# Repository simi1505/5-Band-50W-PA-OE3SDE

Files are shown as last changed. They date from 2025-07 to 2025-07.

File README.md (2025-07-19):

# 5-Band-50W-PA-OE3SDE
 50W 5-Band (80m, 40m, 30m, 20m and 10m) SSB PA inspired by W6JL.

## Block Diagram

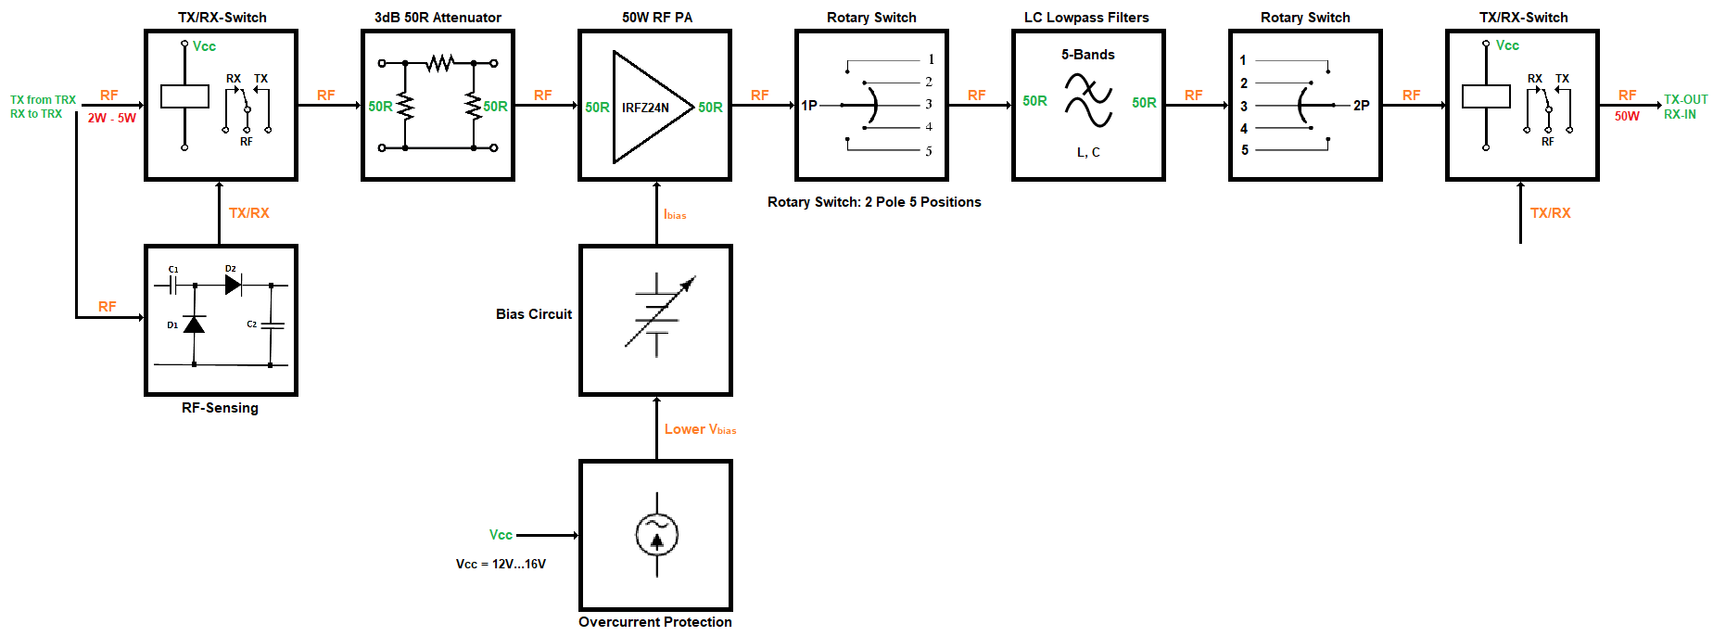
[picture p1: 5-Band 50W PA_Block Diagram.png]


**Figure 1**: Block diagram of 50W 5-Band (80m, 40m, 30m, 20m and 10m) SSB PA.

## Results

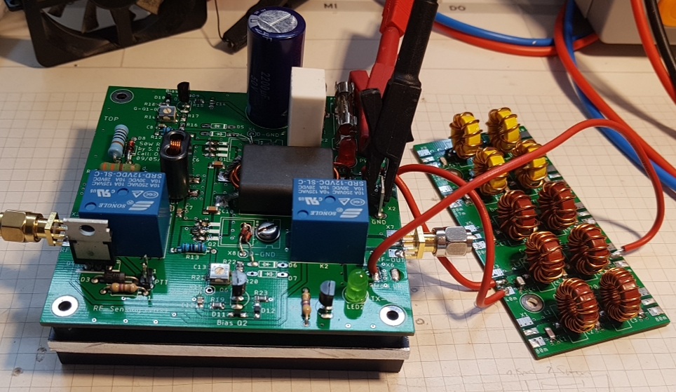
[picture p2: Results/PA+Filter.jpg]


**Figure 2**: Setup of 50W PA and LC lowpass filter.

## LC Lowpass Filters

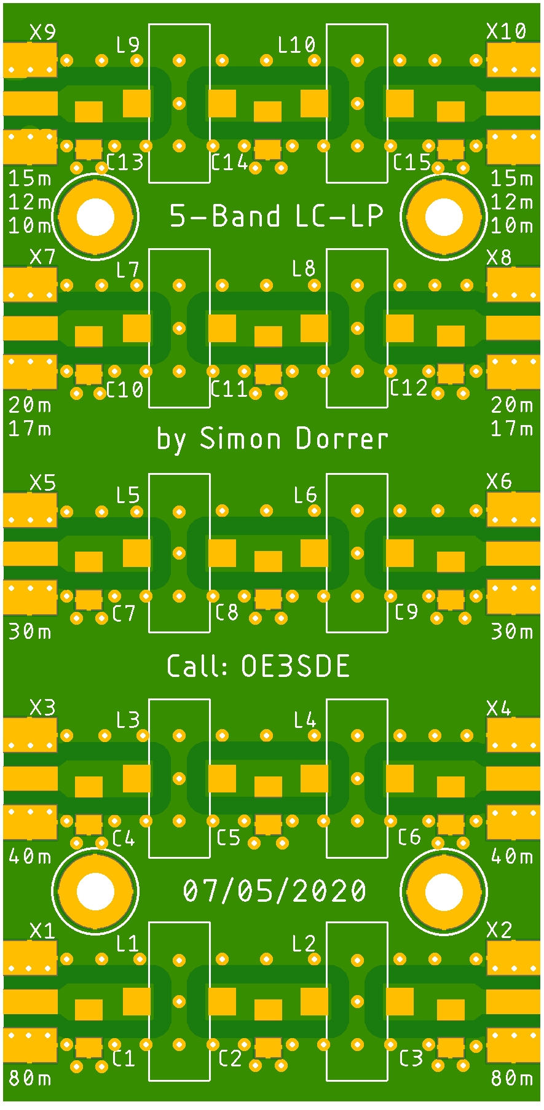
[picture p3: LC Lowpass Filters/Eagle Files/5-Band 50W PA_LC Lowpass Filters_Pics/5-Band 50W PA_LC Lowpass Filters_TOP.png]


**Figure 3**: Top view of LC lowpass filter PCB.



**Figure 4**: Measurement of LC lowpass filter with NanoVNA.

## **50W Power Amplifier**

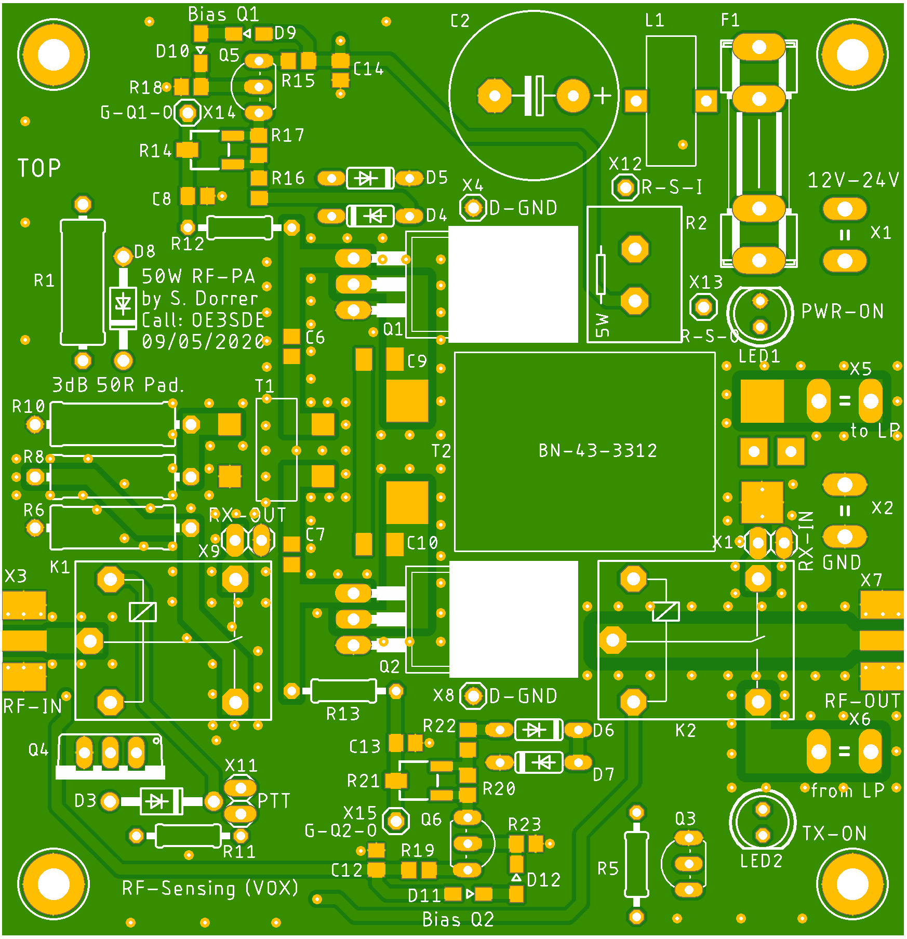
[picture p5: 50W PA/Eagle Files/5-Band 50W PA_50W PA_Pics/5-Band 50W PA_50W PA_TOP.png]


**Figure 5**: Top view of 50W PA PCB.

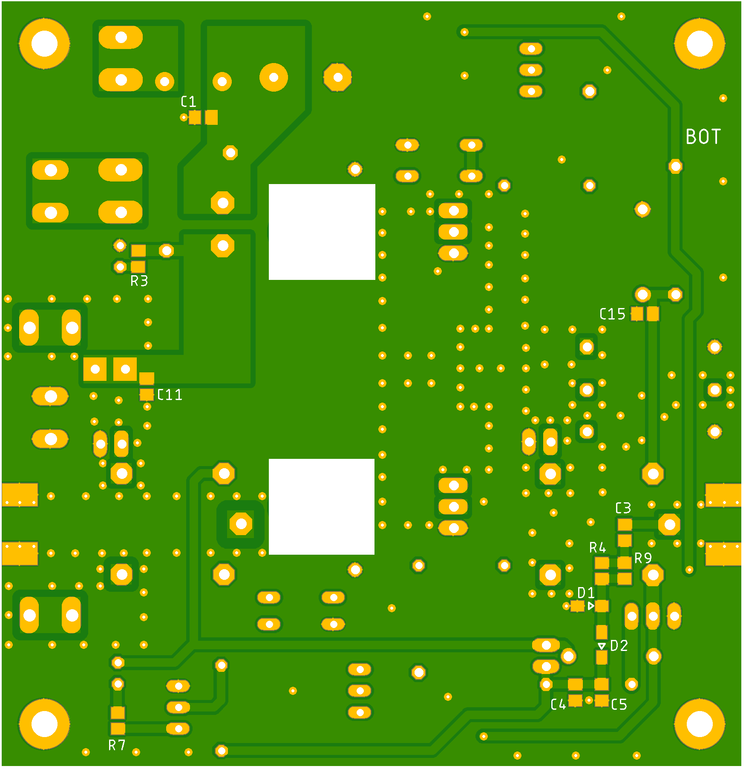
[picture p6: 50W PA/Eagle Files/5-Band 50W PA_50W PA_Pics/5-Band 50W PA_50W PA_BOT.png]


**Figure 6**: Bottom view of 50W PA PCB.

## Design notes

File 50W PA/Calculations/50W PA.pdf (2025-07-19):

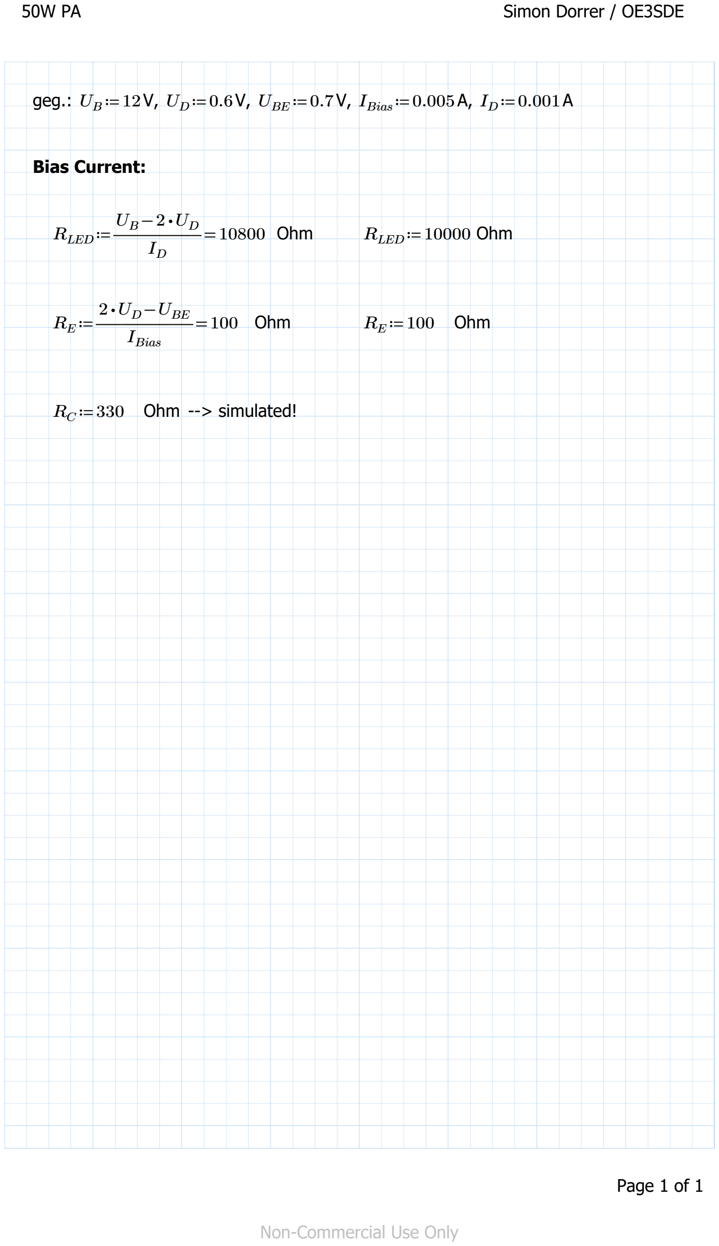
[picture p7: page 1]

50W PA | Simon Dorrer / OE3SDE

geg.: UB≔12V, UD≔0.6V, UBE≔0.7V, IBias≔0.005A, ID≔0.001A

Bias Current:

RLED≔――――=

UB −2 ⋅UD
ID

10800 Ohm RLED≔10000 Ohm

RE≔――――=

2 ⋅UD −UBE

IBias

100 Ohm | RE≔100 Ohm

RC≔330 Ohm --> simulated!

Non-Commercial Use Only

Page 1 of 1

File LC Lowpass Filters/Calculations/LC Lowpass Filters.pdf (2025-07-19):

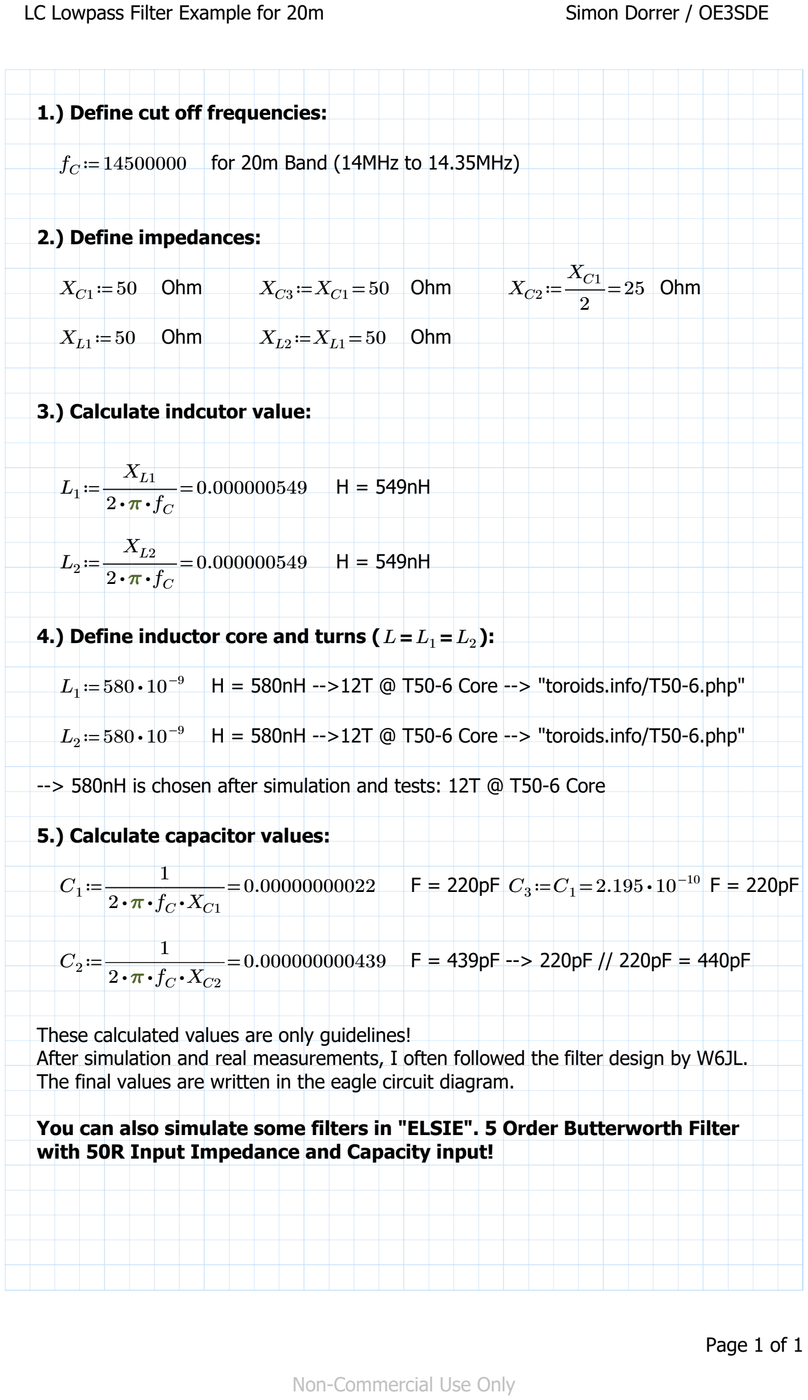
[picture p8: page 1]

LC Lowpass Filter Example for 20m | Simon Dorrer / OE3SDE

1.) Define cut off frequencies:

fC≔14500000 for 20m Band (14MHz to 14.35MHz)

2.) Define impedances:
XC1≔50 Ohm | XC3≔XC1=50 Ohm | XC2≔――= XC1
| | 2

### 25 Ohm

XL1≔50 Ohm XL2≔XL1=50 Ohm

3.) Calculate indcutor value:

L1≔―――=

XL1
2 ⋅π⋅ fC

0.000000549 H = 549nH

L2≔―――=

XL2
2 ⋅π⋅ fC
0.000000549 | H = 549nH
4.) Define inductor core and turns (L＝L ＝ ): 1 | L2

L1≔580 ⋅ 10⁻⁹ H = 580nH -->12T @ T50-6 Core --> "toroids.info/T50-6.php"

L2≔580 ⋅ 10⁻⁹ H = 580nH -->12T @ T50-6 Core --> "toroids.info/T50-6.php"

--> 580nH is chosen after simulation and tests: 12T @ T50-6 Core

5.) Calculate capacitor values:

C1≔―――――=

1
2 ⋅π⋅ fC ⋅XC1

0.00000000022 F = 220pF C3≔C1=2.195 ⋅ 10⁻¹⁰ F = 220pF

C2≔―――――=

1
2 ⋅π⋅ fC ⋅XC2

0.000000000439 F = 439pF --> 220pF // 220pF = 440pF

These calculated values are only guidelines!
After simulation and real measurements, I often followed the filter design by W6JL. The final values are written in the eagle circuit diagram.

You can also simulate some filters in "ELSIE". 5 Order Butterworth Filter with 50R Input Impedance and Capacity input!

Non-Commercial Use Only

Page 1 of 1

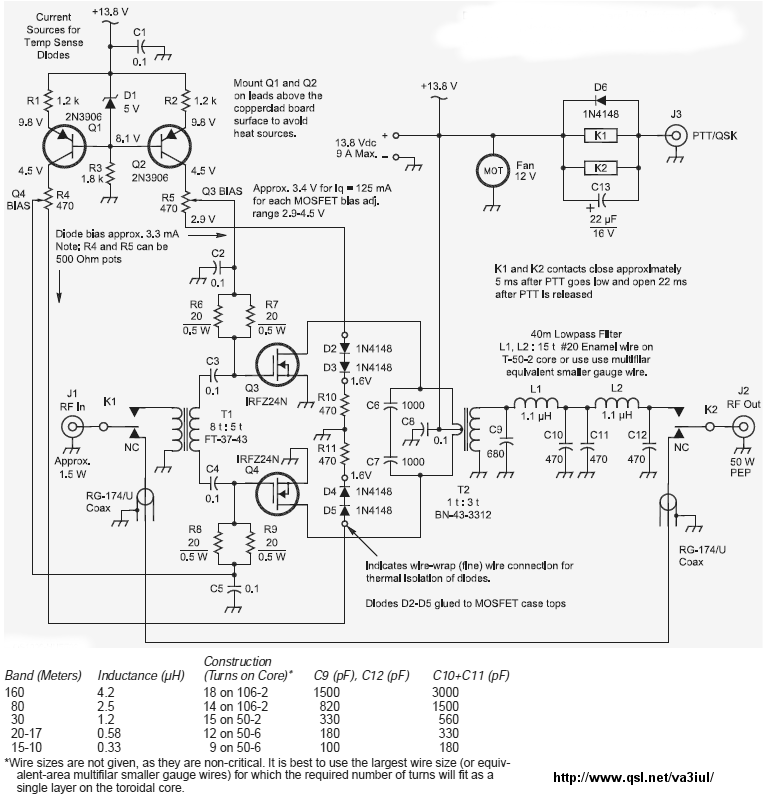
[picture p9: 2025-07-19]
5-Band 50W PA W6JL.gif

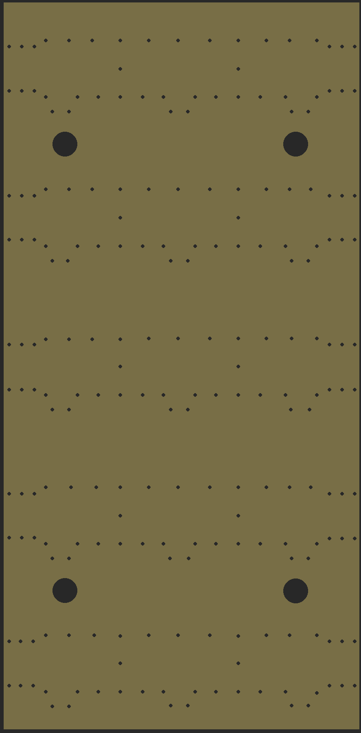
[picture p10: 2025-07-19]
LC Lowpass Filters/Eagle Files/5-Band 50W PA_LC Lowpass Filters_Pics/5-Band 50W PA_LC Lowpass Filters_Drills.png

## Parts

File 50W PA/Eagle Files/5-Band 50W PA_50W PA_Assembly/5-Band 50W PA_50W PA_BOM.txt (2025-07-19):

Partlist exported from E:/Simon Dorrer/DIY Projekte/Amateurfunkprojekte/DIY KITs/HF/5-Band 50W PA/50W PA/Eagle Files/5-Band 50W PA_50W PA.sch at 16/06/2020 14:54

Qty Value               Device                      Package                  Parts                                       Description                                                     MF                 MPN          OC_FARNELL OC_NEWARK POPULARITY SPICEPREFIX
1   0.10R/5W            RMNS-5                      MNS-5                    R2                                          Power Resitor                                                                                   unknown    unknown                         
2   100R                R-EU_R0805                  R0805                    R15, R19                                    RESISTOR, European symbol                                                                                            86         R          
1   100R/1W             R-EU_0414/15                0414/15                  R1                                          RESISTOR, European symbol                                                                                            0          R          
10  100nF               C-EUC0805                   C0805                    C1, C4, C6, C7, C8, C11, C12, C13, C14, C15 CAPACITOR, European symbol                                                                                           88         C          
2   10R                 R-EU_0207/10                0207/10                  R12, R13                                    RESISTOR, European symbol                                                                                            81         R          
2   10k                 R-EU_R0805                  R0805                    R18, R23                                    RESISTOR, European symbol                                                                                            86         R          
1   12V                 ST6,3                       ST6,3                    X1                                          RIBBON CABLE CONNECTOR                                                                          unknown    unknown                         
1   18R/1W              R-EU_0414/15                0414/15                  R8                                          RESISTOR, European symbol                                                                                            0          R          
1   1N4004              1N4004                      DO41-10                  D3                                          DIODE                                                                                                                                      
4   1N4148              1N4148DO35-7                DO35-7                   D4, D5, D6, D7                              DIODE                                                                                                                                      
6   1N4148              DIODE-SOD323-W              SOD323-W                 D1, D2, D9, D10, D11, D12                   DIODE                                                                                                                                      
1   1N4740A             1N4728                      DO41Z10                  D8                                          Z DIODE                                                                                                                                    
3   1k                  R-EU_R0805                  R0805                    R7, R17, R20                                RESISTOR, European symbol                                                                                            86         R          
2   1k                  TRIM_EU-3223G               3223G                    R14, R21                                    POTENTIOMETER                                                                                                                              
1   1nF                 C-EUC0805                   C0805                    C3                                          CAPACITOR, European symbol                                                                                           88         C          
2   1nF                 C-EUC1206K                  C1206K                   C9, C10                                     CAPACITOR, European symbol                                                                                           13         C          
1   1uF                 C-EUC0805                   C0805                    C5                                          CAPACITOR, European symbol                                                                                           88         C          
1   2200uF/25V          CPOL-EUE7.5-16              E7,5-16                  C2                                          POLARIZED CAPACITOR, European symbol                                                                                 4          C          
1   2k                  R-EU_R0805                  R0805                    R3                                          RESISTOR, European symbol                                                                                            86         R          
2   300R/1W             R-EU_0414/15                0414/15                  R6, R10                                     RESISTOR, European symbol                                                                                            0          R          
2   330R                R-EU_R0805                  R0805                    R16, R22                                    RESISTOR, European symbol                                                                                            86         R          
2   470R/0.5W           R-EU_0207/10                0207/10                  R5, R11                                     RESISTOR, European symbol                                                                                            81         R          
1   10A                  SHK20L                      SHK20L                   F1                                          FUSE HOLDER 5 x 20 mm, SH contact, SHH1 Schukat, E1073 Buerklin                                 unknown    unknown                         
2   680R                R-EU_R0805                  R0805                    R4, R9                                      RESISTOR, European symbol                                                                                            86         R          
1   BC547B              BC547B-NPN-TO92-CBE         TO92-CBE                 Q3                                          NPN Transistror                                                                                                                            
2   BC557B              BC557B                      TO92-EBC                 Q5, Q6                                      PNP Transistror                                                                                                                            
1   BN-43-3312          BN-43-3312CENTERTAP         BN-43-3312CENTERTAPSMD   T2                                                                                                                                                                                     
1   FT37-43             FT37-43                     FT37-43SMD               T1                                                                                                                                                                                     
1   G-Q1_OUT            PINHD-1X1                   1X01                     X14                                         PIN HEADER                                                                                                                                 
1   G-Q2_OUT            PINHD-1X1                   1X01                     X15                                         PIN HEADER                                                                                                                                 
4   GND                 MOUNT-PAD-ROUND3.0          3,0-PAD                  H1, H2, H3, H4                              MOUNTING PAD, round                                                                                                                        
2   GND                 PINHD-1X1                   1X01                     X4, X8                                      PIN HEADER                                                                                                                                 
1   GND                 ST6,3                       ST6,3                    X2                                          RIBBON CABLE CONNECTOR                                                                          unknown    unknown                         
2   IRFZ24              IRF510                      TO220                    Q1, Q2                                      N-Channel Enhancement MOSFET (HEXFET); 100V; 5,6A; 0,54Ohm                                                                                 
1   LP-IN               ST6,3                       ST6,3                    X5                                          RIBBON CABLE CONNECTOR                                                                          unknown    unknown                         
1   LP-O                ST6,3                       ST6,3                    X6                                          RIBBON CABLE CONNECTOR                                                                          unknown    unknown                         
1   PTT                 PINHD-1X2                   1X02                     X11                                         PIN HEADER                                                                                                                                 
1   R-Shunt_OUT         PINHD-1X1                   1X01                     X13                                         PIN HEADER                                                                                                                                 
1   RF-IN               SMA-PCB-CON142-0711-821/826 J502-ND-142-0711-821/826 X3                                          SMA 50 Ohm End Launch Jack Receptacle - Round Contact           JOHNSON COMPONENTS 142-0711-821 1019328    16F3627                         
1   RF-OUT              SMA-PCB-CON142-0711-821/826 J502-ND-142-0711-821/826 X7                                          SMA 50 Ohm End Launch Jack Receptacle - Round Contact           JOHNSON COMPONENTS 142-0711-821 1019328    16F3627                         
1   RX-IN               PINHD-1X2                   1X02                     X10                                         PIN HEADER                                                                                                                                 
1   RX-OUT              PINHD-1X2                   1X02                     X9                                          PIN HEADER                                                                                                                                 
1   R_Shunt_IN          PINHD-1X1                   1X01                     X12                                         PIN HEADER                                                                                                                                 
2   Red                 LED5MM                      LED5MM                   LED1, LED2                                  LED                                                                                                                                        
2   SRD-12VDC-SL-C      SRD-12VDC-SL-C              SRD-12VDC-SL-C           K1, K2                                      RELAY                                                                                                                                      
1   TIP31C              TIP41C                      TO220AV                  Q4                                          NPN TRANSISTOR                                                                                                                             
1   RFC T50-6                       T50-6SMD                 L1

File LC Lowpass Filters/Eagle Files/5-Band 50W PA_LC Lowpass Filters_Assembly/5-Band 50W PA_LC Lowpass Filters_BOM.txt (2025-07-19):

Partlist exported from E:/Simon Dorrer/DIY Projekte/Amateurfunkprojekte/DIY KITs/5-Band 50W PA/LC Lowpass Filters/Eagle Files/5-Band 50W PA_LC Lowpass Filters.sch at 19/05/2020 19:35

Qty Value   Device               Package                  Parts               Description                                           MF                 MPN          OC_FARNELL OC_NEWARK POPULARITY SPICEPREFIX
2   1.2uH   T50-6                T50-6SMD                 L3, L4                                                                                                                                               
1   1000pF  C-EUC1206K           C1206K                   C5                  CAPACITOR, European symbol                                                                                 13         C          
1   1500pF  C-EUC1206K           C1206K                   C2                  CAPACITOR, European symbol                                                                                 13         C          
1   164pF   C-EUC1206K           C1206K                   C14                 CAPACITOR, European symbol                                                                                 13         C          
2   180pF   C-EUC1206K           C1206K                   C10, C12            CAPACITOR, European symbol                                                                                 13         C          
2   1uH     T50-6                T50-6SMD                 L5, L6                                                                                                                                               
2   2.5uH   T50-6                T50-6SMD                 L1, L2                                                                                                                                               
3   330pF   C-EUC1206K           C1206K                   C7, C9, C11         CAPACITOR, European symbol                                                                                 13         C          
2   400nH   T50-6                T50-6SMD                 L9, L10                                                                                                                                              
3   560pF   C-EUC1206K           C1206K                   C4, C6, C8          CAPACITOR, European symbol                                                                                 13         C          
2   580nH   T50-6                T50-6SMD                 L7, L8                                                                                                                                               
2   820pF   C-EUC1206K           C1206K                   C1, C3              CAPACITOR, European symbol                                                                                 13         C          
2   82pF    C-EUC1206K           C1206K                   C13, C15            CAPACITOR, European symbol                                                                                 13         C          
4   GND     MOUNT-PAD-ROUND3.0   3,0-PAD                  H1, H2, H3, H4      MOUNTING PAD, round                                                                                                              
5   SMA_IN  SMA-142-0711-821/826 J502-ND-142-0711-821/826 X1, X3, X5, X7, X9  SMA 50 Ohm End Launch Jack Receptacle - Round Contact JOHNSON COMPONENTS 142-0711-821 1019328    16F3627                         
5   SMA_OUT SMA-142-0711-821/826 J502-ND-142-0711-821/826 X2, X4, X6, X8, X10 SMA 50 Ohm End Launch Jack Receptacle - Round Contact JOHNSON COMPONENTS 142-0711-821 1019328    16F3627

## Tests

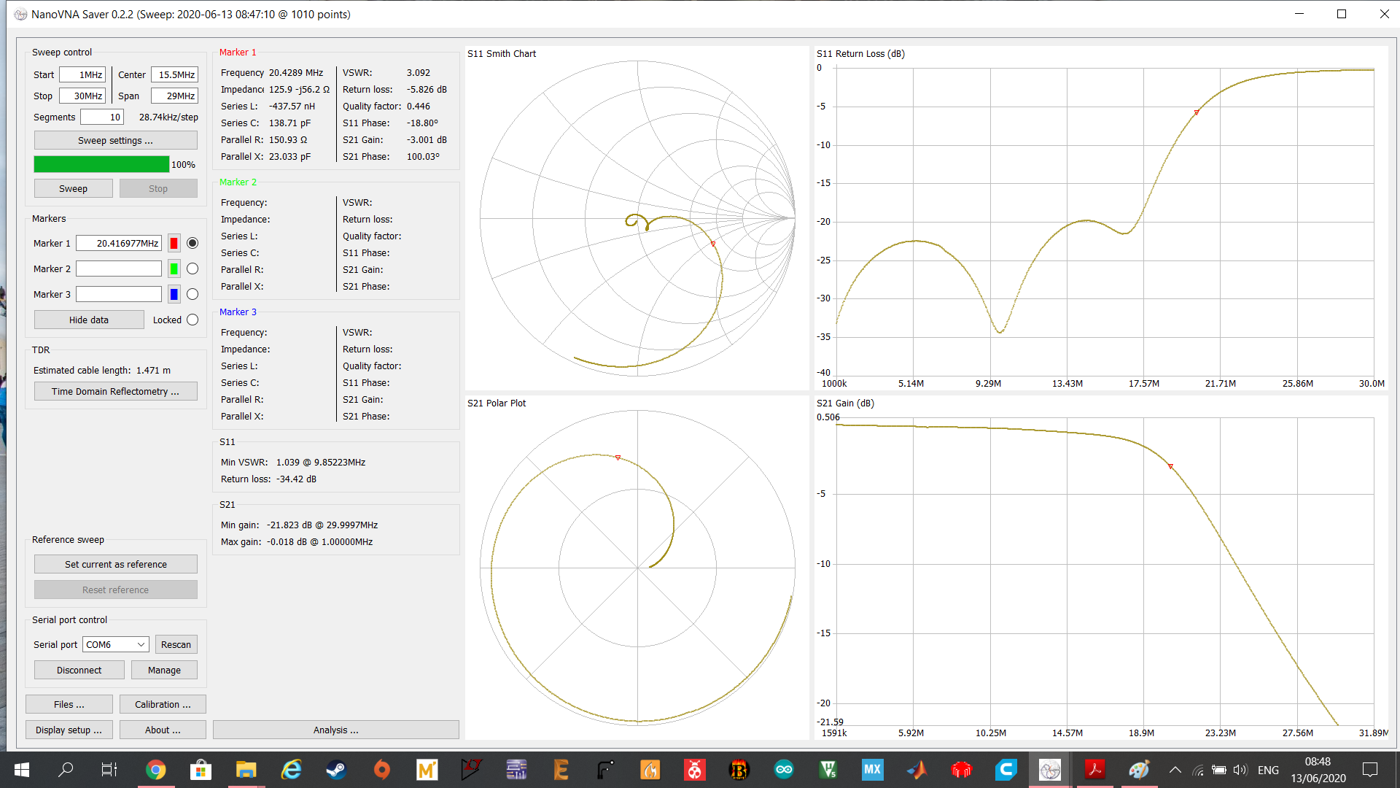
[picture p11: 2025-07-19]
LC Lowpass Filters/Measurements/20m.png

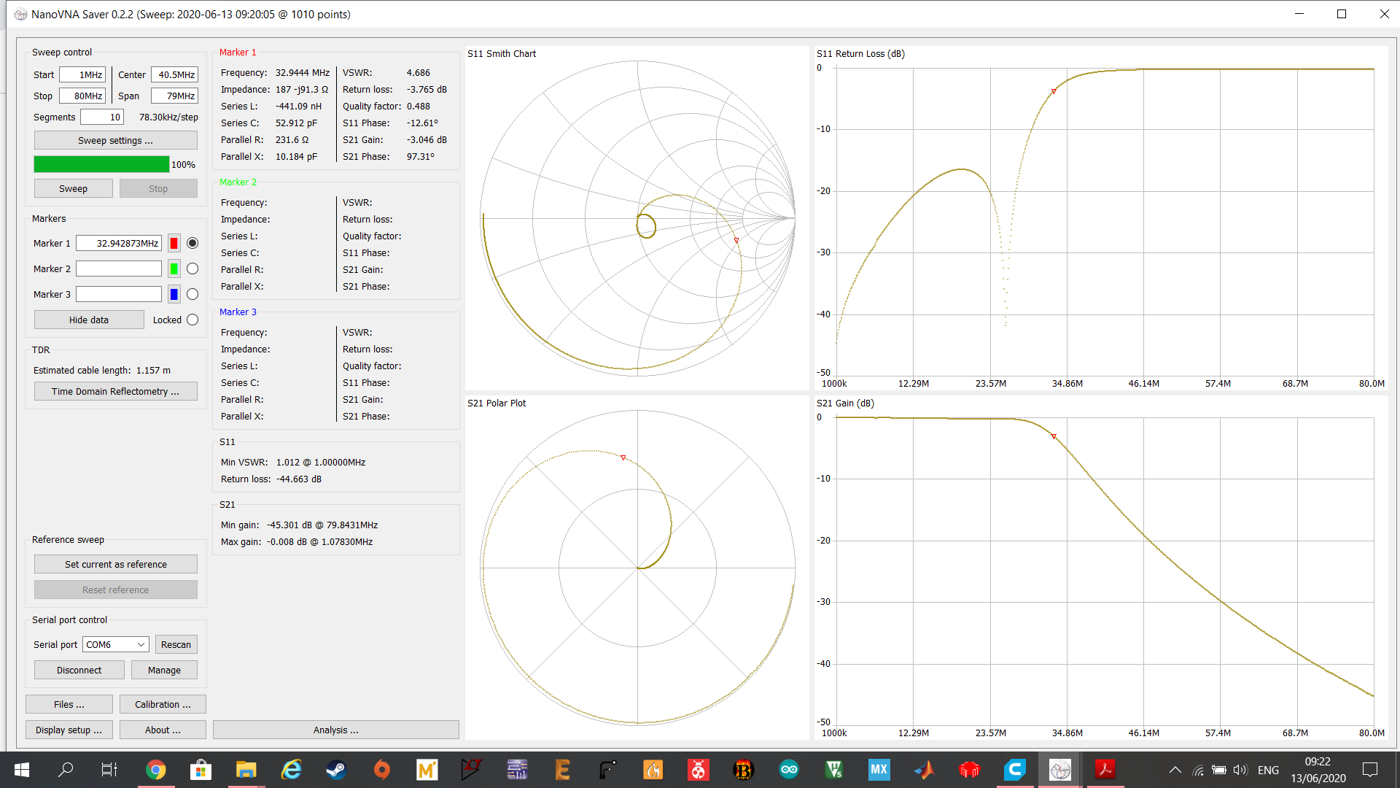
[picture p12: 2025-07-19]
LC Lowpass Filters/Measurements/15-12-10m.png

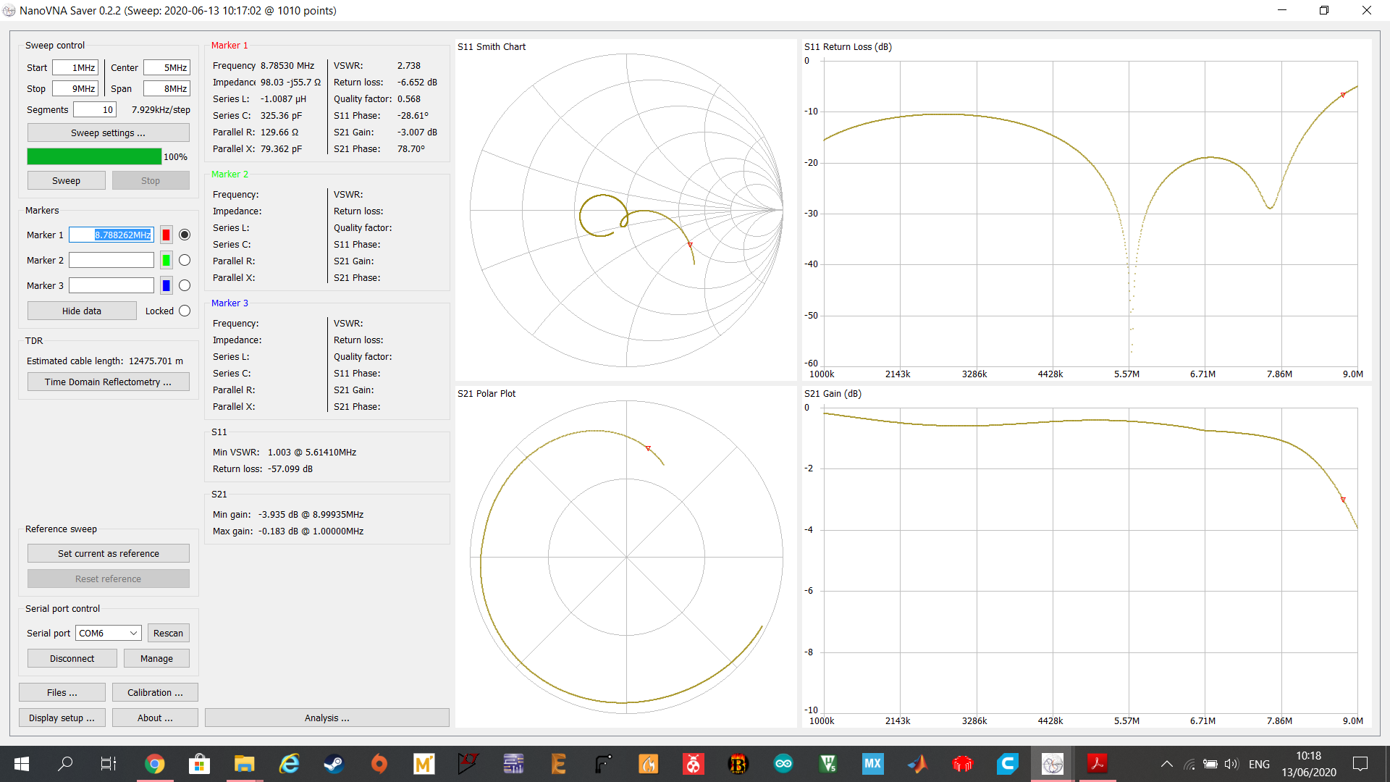
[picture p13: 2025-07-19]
LC Lowpass Filters/Measurements/40m_2.png

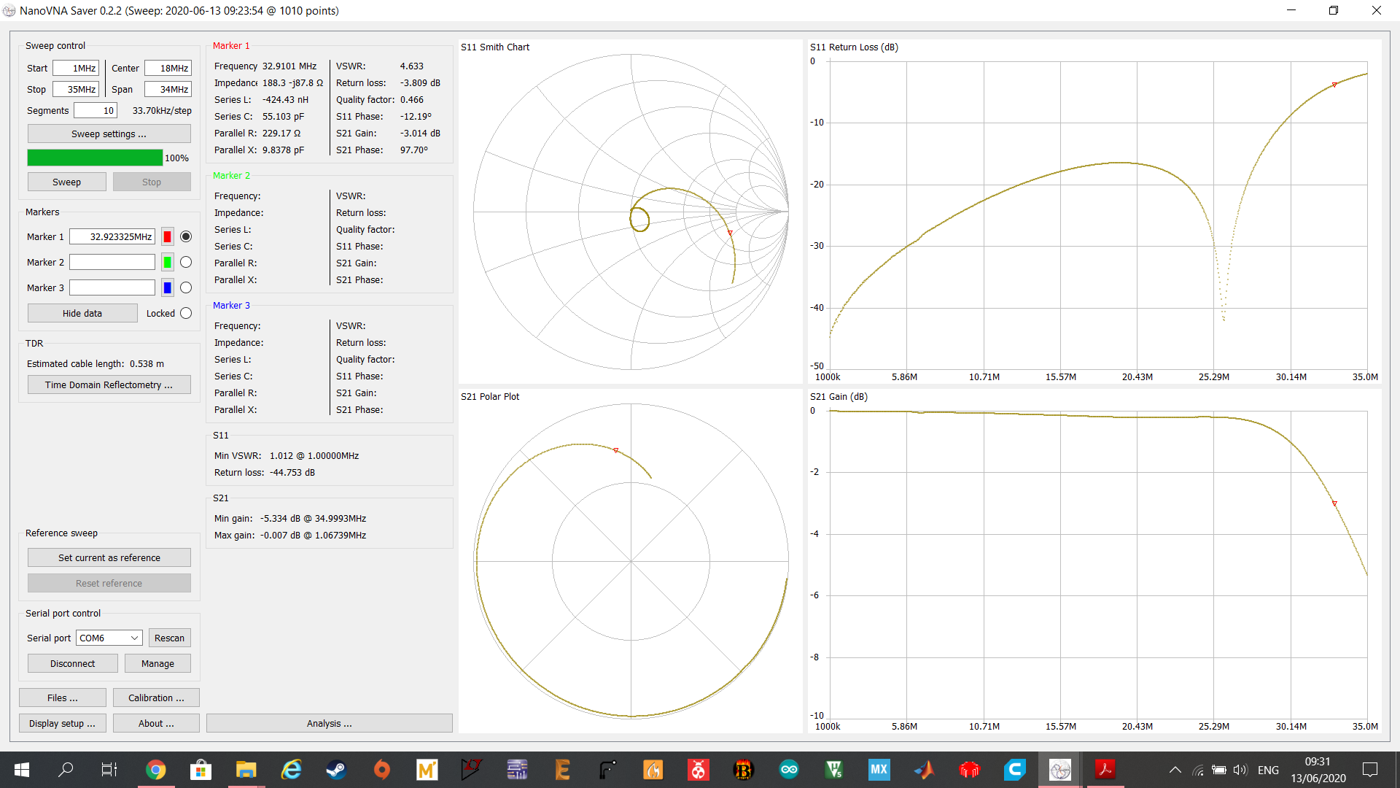
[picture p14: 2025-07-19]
LC Lowpass Filters/Measurements/15-12-10m_2.png

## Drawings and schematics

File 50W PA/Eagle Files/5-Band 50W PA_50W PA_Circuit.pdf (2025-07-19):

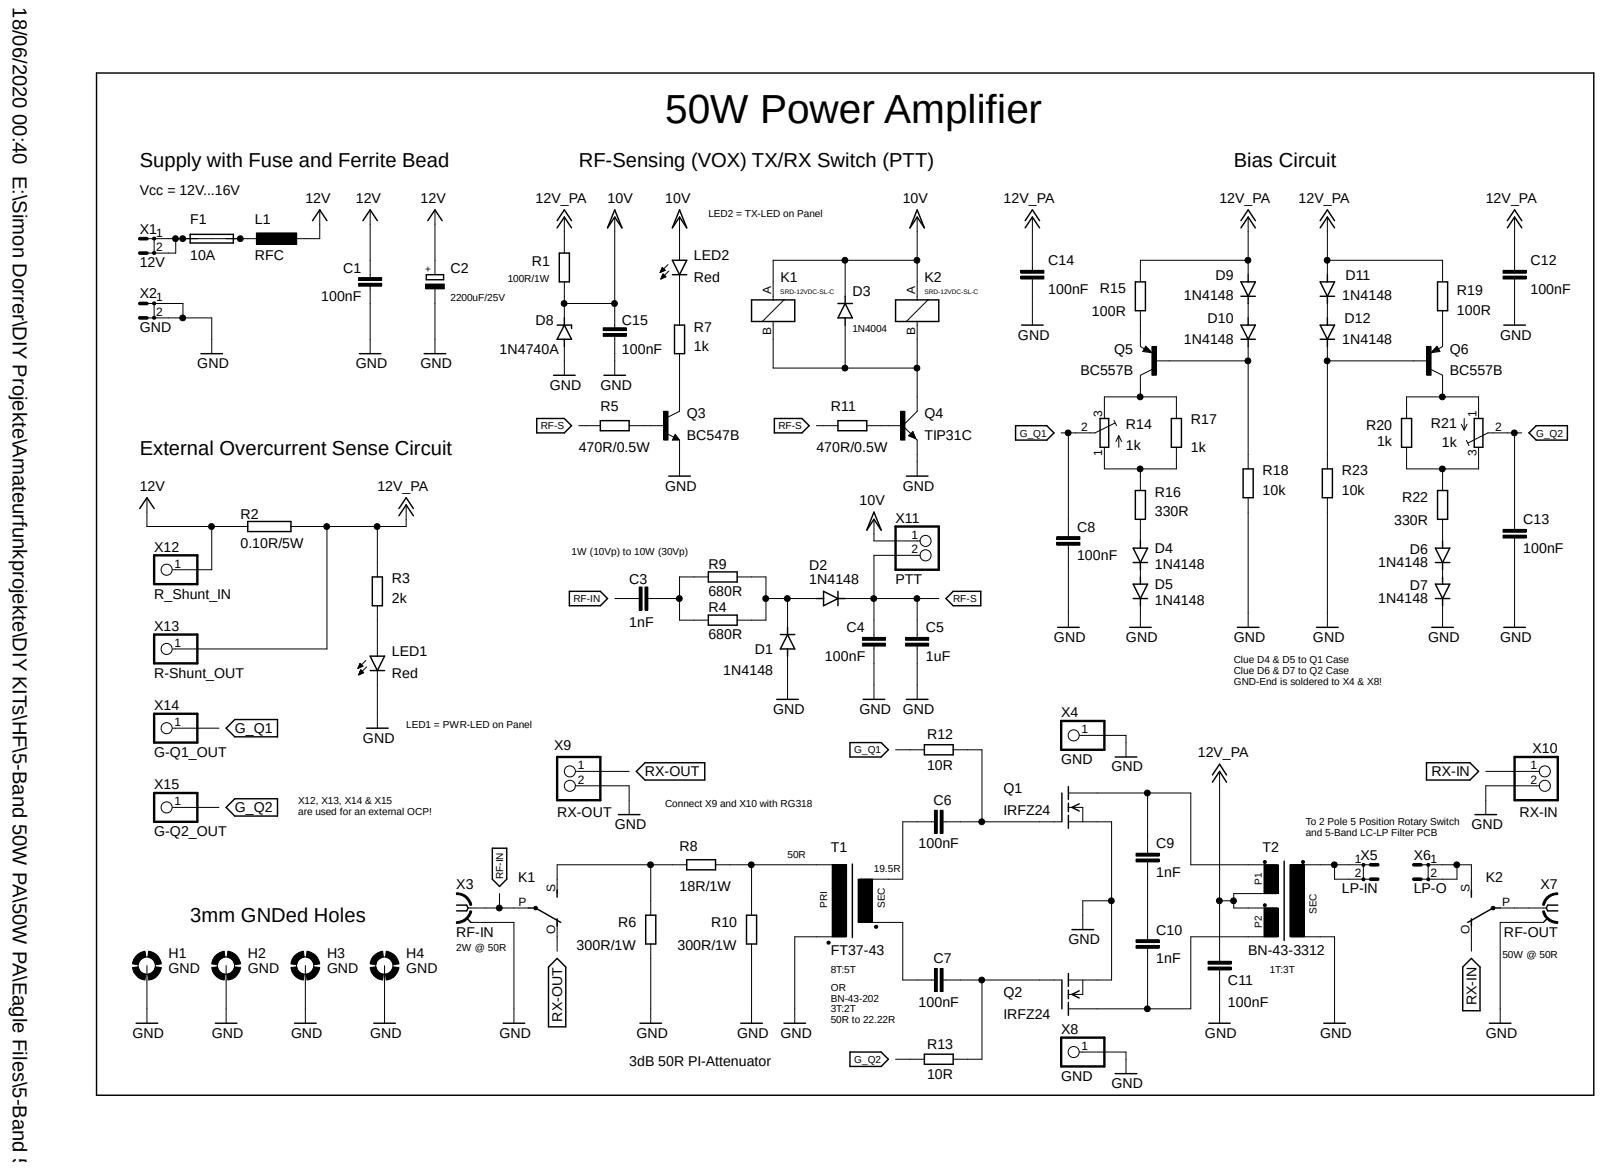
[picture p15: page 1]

18/06/2020 00:40 E:\Simon Dorrer\DIY Projekte\Amateurfunkprojekte\DIY KITs\HF\5-Band 50W PA\50W PA\Eagle Files\5-Band 50W PA_50W PA.sch (Sheet: 1/1) 2W @ 50R 50W @ 50R Clue D4 & D5 to Q1 Case Clue D6 & D7 to Q2 Case GND-End is soldered to X4 & X8! 8T:5T 1T:3T 50W Power Amplifier Supply with Fuse and Ferrite Bead Bias Circuit 3mm GNDed Holes External Overcurrent Sense Circuit RF-Sensing (VOX) TX/RX Switch (PTT) 3dB 50R PI-Attenuator Vcc = 12V...16V To 2 Pole 5 Position Rotary Switch and 5-Band LC-LP Filter PCB LED1 = PWR-LED on Panel 1W (10Vp) to 10W (30Vp) LED2 = TX-LED on Panel Connect X9 and X10 with RG318 X12, X13, X14 & X15 are used for an external OCP! 50R 19.5R ORBN-43-202 3T:2T 50R to 22.22R GND 100nF GND 12V IRFZ24 IRFZ24 RF-IN RF-OUT GND 100nF 100nF GND 100nF GND BC557B BC557B GND 2200uF/25V GND 100nF 100nF 100R 100R 1k 1k 1k 1k 330R 330R 1N4148 1N4148 1N4148 1N4148 GND GND GND GND 10k GND 10R 10R GND GND GND GND GND GND GND GND GND 18R/1W 300R/1W 300R/1W GND GND GND 1N4004 GND 470R/0.5W 1N4148 1N4148 100nF 1uF GND GND 1nF GND GND100nF 10A 12V GND RFC BC547B 470R/0.5W 1kRed 12V GND GND 2kRed GND LP-IN LP-O 12V_PA 12V_PA FT37-43 BN-43-3312 1nF 1nF GND GND GND TIP31C GND100nF GND GND 10k GND 680R 680R PTT 12V_PA 12V_PA 12V_PA 12V_PA 1N4740A 12V_PA GND 10V 10V 10V 0.10R/5W 100nF GND 10V 1N4148 1N4148 1N4148 1N4148 SRD-12VDC-SL-C SRD-12VDC-SL-C RX-OUT RX-IN R_Shunt_IN R-Shunt_OUT G-Q1_OUT G-Q2_OUT 12V 12V 100R/1W C1 Q1 Q2 X3 X7 C6 C7 C11 Q5 Q6 C2 C8 C13 R15 R19 R17 R20

RX-OUT

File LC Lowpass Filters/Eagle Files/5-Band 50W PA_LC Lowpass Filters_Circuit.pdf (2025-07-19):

23T @ T50-2 | 23T @ T50-2 5-Band LC Lowpass Filters

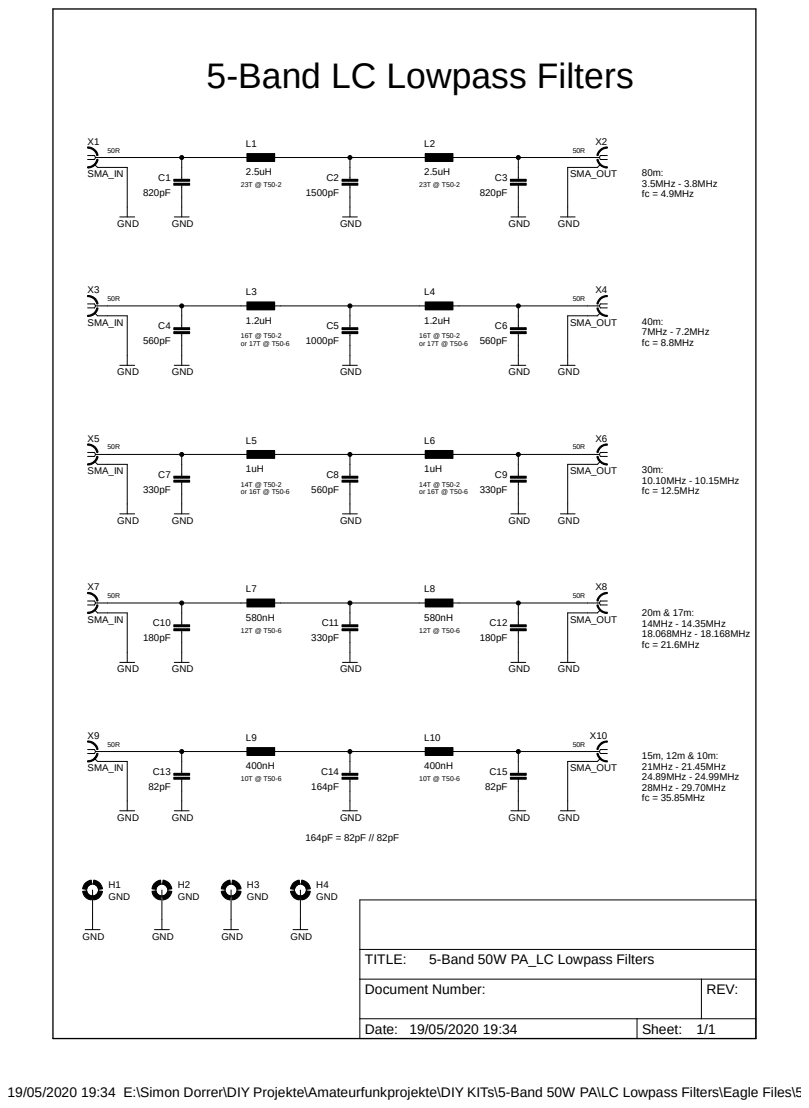
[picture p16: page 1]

Document Number: | REV:

Date: 19/05/2020 19:34 | Sheet: 1/1

19/05/2020 19:34 E:\Simon Dorrer\DIY Projekte\Amateurfunkprojekte\DIY KITs\5-Band 50W PA\LC Lowpass Filters\Eagle Files\5-Band 50W PA_LC Lowpass Filters.sch (Sheet: 1/1)

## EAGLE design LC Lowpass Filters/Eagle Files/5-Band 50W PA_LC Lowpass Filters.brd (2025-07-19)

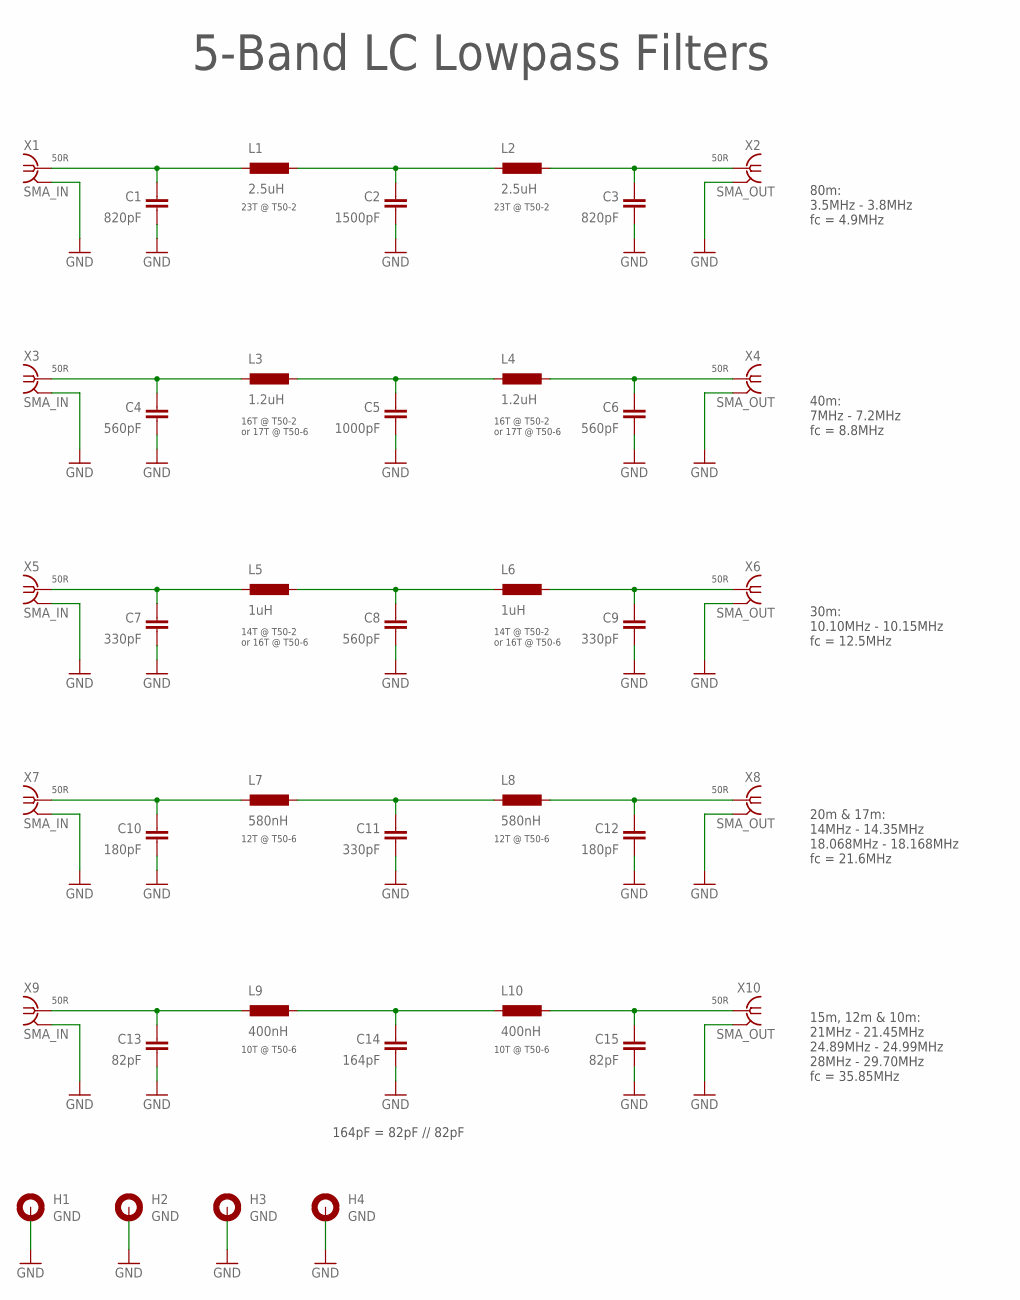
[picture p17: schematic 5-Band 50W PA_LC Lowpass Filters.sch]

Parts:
C1, C3: 820pF; C1206K
C2: 1500pF; C1206K
C4, C6, C8: 560pF; C1206K
C5: 1000pF; C1206K
C7, C9, C11: 330pF; C1206K
C10, C12: 180pF; C1206K
C13, C15: 82pF; C1206K
C14: 164pF; C1206K
H1, H2, H3, H4: GND; 3,0-PAD
L1, L2: 2.5uH; T50-6SMD
L3, L4: 1.2uH; T50-6SMD
L5, L6: 1uH; T50-6SMD
L7, L8: 580nH; T50-6SMD
L9, L10: 400nH; T50-6SMD
X1, X3, X5, X7, X9: SMA_IN; J502-ND-142-0711-821/826
X2, X4, X6, X8, X10: SMA_OUT; J502-ND-142-0711-821/826

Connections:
GND: C1.1, C2.1, C3.1, C4.1, C5.1, C6.1, C7.1, C8.1, C9.1, C10.1, C11.1, C12.1, C13.1, C14.1, C15.1, H1.B3,0, H2.B3,0, H3.B3,0, H4.B3,0, X1.G@1 (2), X1.G@2 (2), X1.G@3 (2), X1.G@4 (2), X2.G@1 (2), X2.G@2 (2), X2.G@3 (2), X2.G@4 (2), X3.G@1 (2), X3.G@2 (2), X3.G@3 (2), X3.G@4 (2), X4.G@1 (2), X4.G@2 (2), X4.G@3 (2), X4.G@4 (2), X5.G@1 (2), X5.G@2 (2), X5.G@3 (2), X5.G@4 (2), X6.G@1 (2), X6.G@2 (2), X6.G@3 (2), X6.G@4 (2), X7.G@1 (2), X7.G@2 (2), X7.G@3 (2), X7.G@4 (2), X8.G@1 (2), X8.G@2 (2), X8.G@3 (2), X8.G@4 (2), X9.G@1 (2), X9.G@2 (2), X9.G@3 (2), X9.G@4 (2), X10.G@1 (2), X10.G@2 (2), X10.G@3 (2), X10.G@4 (2)
unnamed: C2.2, L1.P$2 (2), L2.P$1 (1)
unnamed: C4.2, L3.P$1 (1), X3.1
unnamed: C3.2, L2.P$2 (2), X2.1
unnamed: C1.2, L1.P$1 (1), X1.1
unnamed: C6.2, L4.P$2 (2), X4.1
unnamed: C5.2, L3.P$2 (2), L4.P$1 (1)
unnamed: C7.2, L5.P$1 (1), X5.1
unnamed: C9.2, L6.P$2 (2), X6.1
unnamed: C8.2, L5.P$2 (2), L6.P$1 (1)
unnamed: C10.2, L7.P$1 (1), X7.1
unnamed: C12.2, L8.P$2 (2), X8.1
unnamed: C11.2, L7.P$2 (2), L8.P$1 (1)
unnamed: C13.2, L9.P$1 (1), X9.1
unnamed: C15.2, L10.P$2 (2), X10.1
unnamed: C14.2, L9.P$2 (2), L10.P$1 (1)

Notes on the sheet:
50R
80m: 3.5MHz - 3.8MHz fc = 4.9MHz
23T @ T50-2
5-Band LC Lowpass Filters
40m: 7MHz - 7.2MHz fc = 8.8MHz
16T @ T50-2 or 17T @ T50-6
30m: 10.10MHz - 10.15MHz fc = 12.5MHz
14T @ T50-2 or 16T @ T50-6
20m & 17m: 14MHz - 14.35MHz 18.068MHz - 18.168MHz fc = 21.6MHz
12T @ T50-6
15m, 12m & 10m: 21MHz - 21.45MHz 24.89MHz - 24.99MHz 28MHz - 29.70MHz fc = 35.85MHz
10T @ T50-6
164pF = 82pF // 82pF

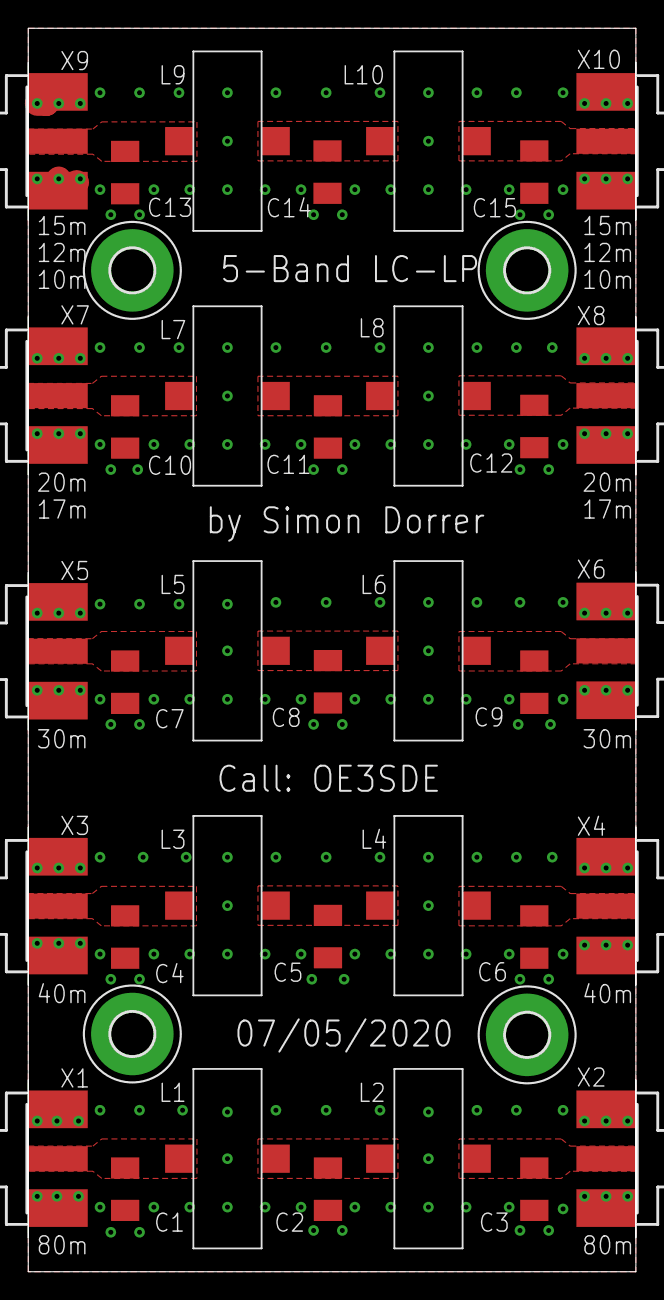
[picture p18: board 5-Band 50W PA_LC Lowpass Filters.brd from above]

Board: 2 copper layers, 43.0 x 88.0 mm, 39 parts (0 on the bottom side), 16 nets.

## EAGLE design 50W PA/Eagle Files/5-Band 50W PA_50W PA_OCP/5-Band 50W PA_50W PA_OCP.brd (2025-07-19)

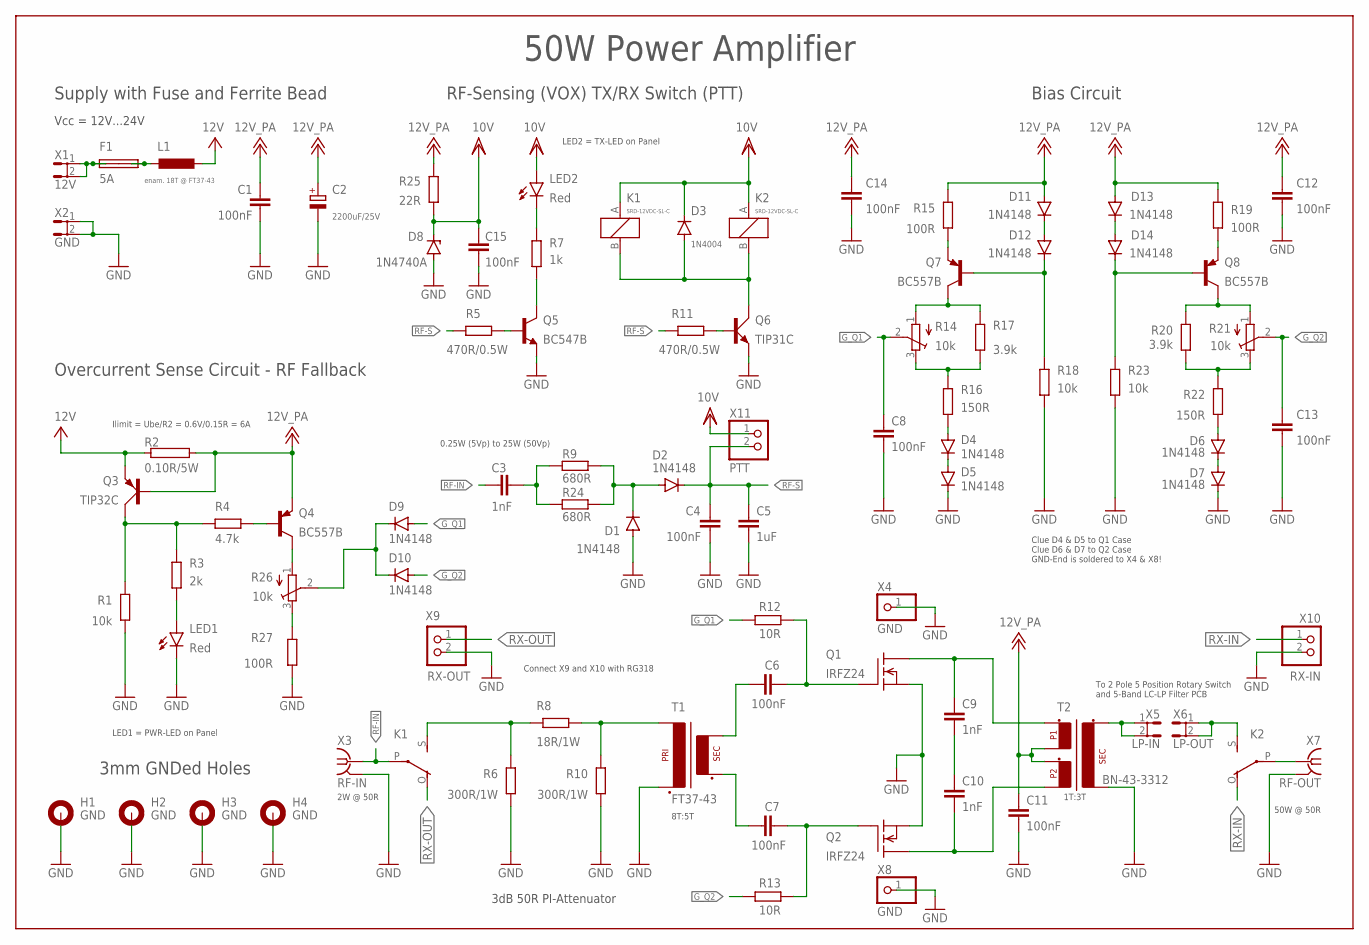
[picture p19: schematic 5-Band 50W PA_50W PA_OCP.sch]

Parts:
C1, C4, C6, C7, C8, C11, C12, C13, C14, C15: 100nF; C0805
C2: 2200uF/25V; E7,5-16
C3: 1nF; C0805
C5: 1uF; C0805
C9, C10: 1nF; C1206K
D1, D2, D9, D10, D11, D12, D13, D14: 1N4148; SOD323-W
D3: 1N4004; DO41-10
D4, D5, D6, D7: 1N4148; DO35-7
D8: 1N4740A; DO41Z10
F1: 5A; SHK20L
H1, H2, H3, H4: GND; 3,0-PAD
K1, K2: SRD-12VDC-SL-C
L1: enam. 18T @ FT37-43; T50-6SMD
LED1, LED2: Red; LED5MM
Q1, Q2: IRFZ24; TO220
Q3: TIP32C; TO220AV
Q4, Q7, Q8: BC557B; TO92-EBC
Q5: BC547B; TO92-CBE
Q6: TIP31C; TO220AV
R1, R18, R23: 10k; R0805
R2: 0.10R/5W; MNS-5
R3: 2k; R0805
R4: 4.7k; R0805
R5, R11: 470R/0.5W; 0207/10
R6, R10: 300R/1W; 0414/15
R7: 1k; R0805
R8: 18R/1W; 0414/15
R9, R24: 680R; R0805
R12, R13: 10R; 0207/10
R14, R21, R26: 10k; 3223G
R15, R19, R27: 100R; R0805
R16, R22: 150R; R0805
R17, R20: 3.9k; R0805
R25: 22R; 0207/10
T1: FT37-43; FT37-43SMD
T2: BN-43-3312; BN-43-3312CENTERTAPSMD
X1: 12V; ST6,3
X2: GND; ST6,3
X3: RF-IN; J502-ND-142-0711-821/826
X4, X8: GND; 1X01
X5: LP-IN; ST6,3
X6: LP-OUT; ST6,3
X7: RF-OUT; J502-ND-142-0711-821/826
X9: RX-OUT; 1X02
X10: RX-IN; 1X02
X11: PTT; 1X02

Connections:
+12V: C1.2, C2.+, C11.2, C12.2, C14.2, D11.A, D13.A, Q3.B, Q4.E, R2.2, R15.2, R19.2, R25.2, T2.P$2 (P1_2), T2.P$3 (P2_1)
GND: C1.1, C2.-, C4.1, C5.1, C8.1, C11.1, C12.1, C13.1, C14.1, C15.1, D1.A, D5.C, D7.C, D8.A, H1.B3,0, H2.B3,0, H3.B3,0, H4.B3,0, LED1.K (C), Q1.3 (S), Q2.3 (S), Q5.E, Q6.E, R1.1, R6.1, R10.1, R18.1, R23.1, R27.1, T1.P$2 (P2), T2.S$2 (S2), X2.1, X2.2, X3.G@1 (GND), X3.G@2 (GND), X3.G@3 (GND), X3.G@4 (GND), X4.1, X7.G@1 (GND), X7.G@2 (GND), X7.G@3 (GND), X7.G@4 (GND), X8.1, X9.2, X10.2
G_Q1: C8.2, D9.A, R12.2, R14.2 (S)
G_Q2: C13.2, D10.A, R13.2, R21.2 (S)
unnamed: C6.2, T1.S$1 (S1)
unnamed: C7.2, T1.S$2 (S2)
unnamed: LED2.K (C), R7.1
unnamed: Q8.C, R20.2, R21.1 (A)
unnamed: Q7.E, R15.1
unnamed: C9.1, Q1.2 (D), T2.P$1 (P1_1)
unnamed: R20.1, R21.3 (E), R22.2
unnamed: C10.2, Q2.2 (D), T2.P$4 (P2_2)
unnamed: K1.S, R6.2, R8.2
unnamed: K2.P, X7.1 (RF)
unnamed: R8.1, R10.2, T1.P$1 (P1)
unnamed: D9.C, D10.C, R26.2 (S)
unnamed: D6.C, D7.A
unnamed: Q8.E, R19.1
unnamed: Q7.C, R14.1 (A), R17.2
unnamed: D4.C, D5.A
unnamed: R14.3 (E), R16.2, R17.1
unnamed: D4.A, R16.1
unnamed: D6.A, R22.1
unnamed: D12.C, Q7.B, R18.2
unnamed: C6.1, Q1.1 (G), R12.1
unnamed: C7.1, Q2.1 (G), R13.1
unnamed: K2.S, X6.1, X6.2
unnamed: D3.A, K1.B, K2.B, Q6.C
unnamed: D1.C, D2.A, R9.1, R24.1
unnamed: D14.C, Q8.B, R23.2
unnamed: Q6.B, R11.1
unnamed: F1.1A, F1.1B, X1.1, X1.2
unnamed: R26.3 (E), R27.2
unnamed: F1.2A, F1.2B, L1.P$1 (1)
unnamed: D11.C, D12.A
unnamed: Q5.C, R7.2
unnamed: Q5.B, R5.1
unnamed: C3.1, R9.2, R24.2
unnamed: Q3.C, R1.2, R3.2, R4.2
unnamed: C9.2, C10.1
unnamed: LED1.A, R3.1
unnamed: Q4.B, R4.1
unnamed: T2.S$1 (S1), X5.1, X5.2
unnamed: D13.C, D14.A
unnamed: Q4.C, R26.1 (A)
RF-IN: C3.2, K1.P, X3.1 (RF)
RF-S: C4.2, C5.2, D2.C, R5.2, R11.2, X11.2
RX-IN: K2.O, X10.1
RX-OUT: K1.O, X9.1
VCC: L1.P$2 (2), Q3.E, R2.1
VDD: C15.2, D3.C, D8.C, K1.A, K2.A, LED2.A, R25.1, X11.1

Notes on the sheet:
2W @ 50R
50W @ 50R
Clue D4 & D5 to Q1 Case Clue D6 & D7 to Q2 Case GND-End is soldered to X4 & X8!
1T:3T
8T:5T
50W Power Amplifier
Bias Circuit
Supply with Fuse and Ferrite Bead
3mm GNDed Holes
Overcurrent Sense Circuit - RF Fallback
RF-Sensing (VOX) TX/RX Switch (PTT)
3dB 50R PI-Attenuator
Vcc = 12V...24V
Ilimit = Ube/R2 = 0.6V/0.15R = 6A
To 2 Pole 5 Position Rotary Switch and 5-Band LC-LP Filter PCB
LED1 = PWR-LED on Panel
0.25W (5Vp) to 25W (50Vp)
LED2 = TX-LED on Panel
Connect X9 and X10 with RG318

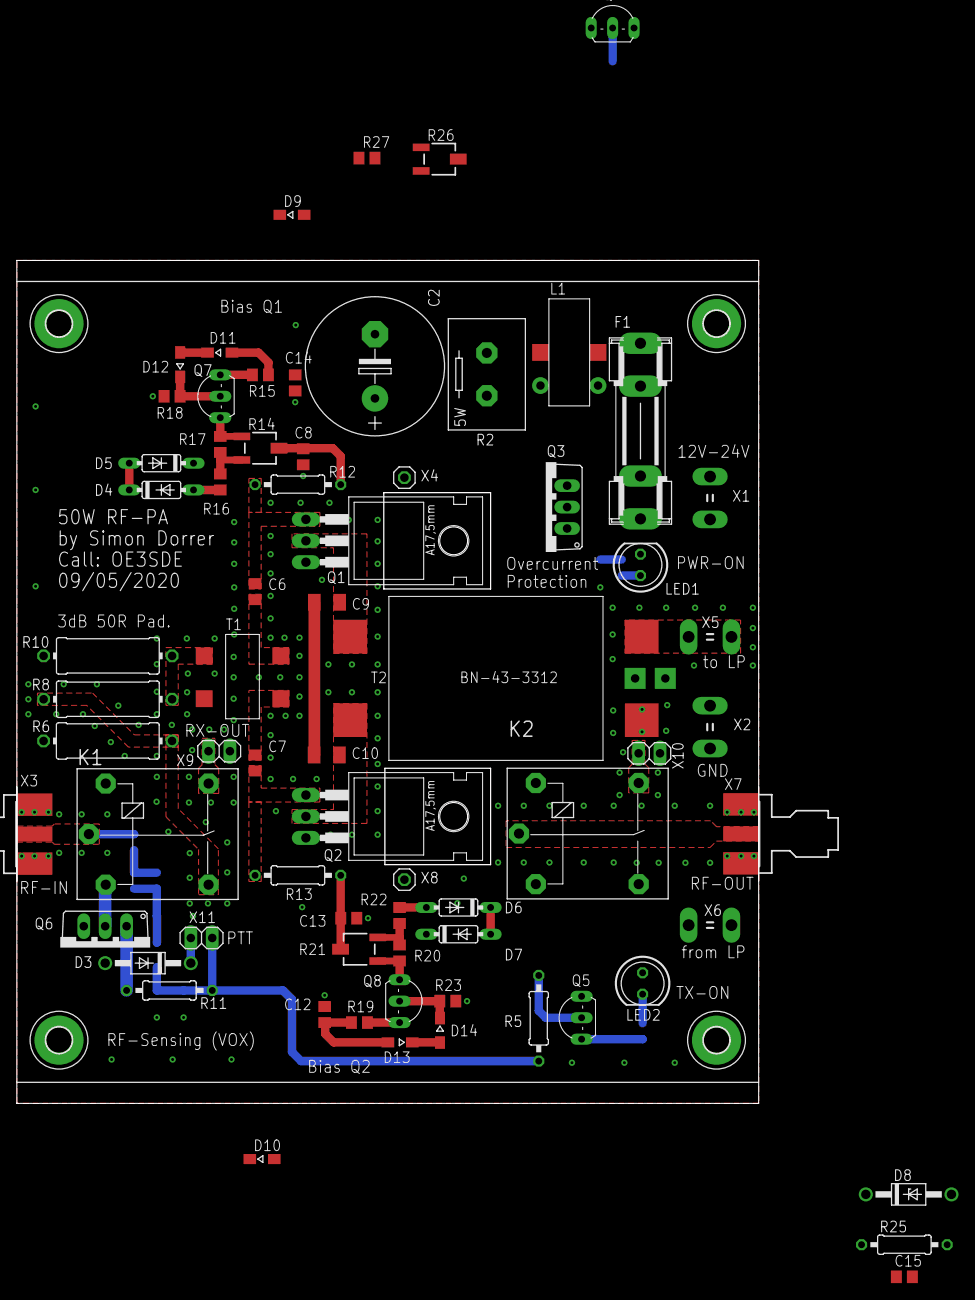
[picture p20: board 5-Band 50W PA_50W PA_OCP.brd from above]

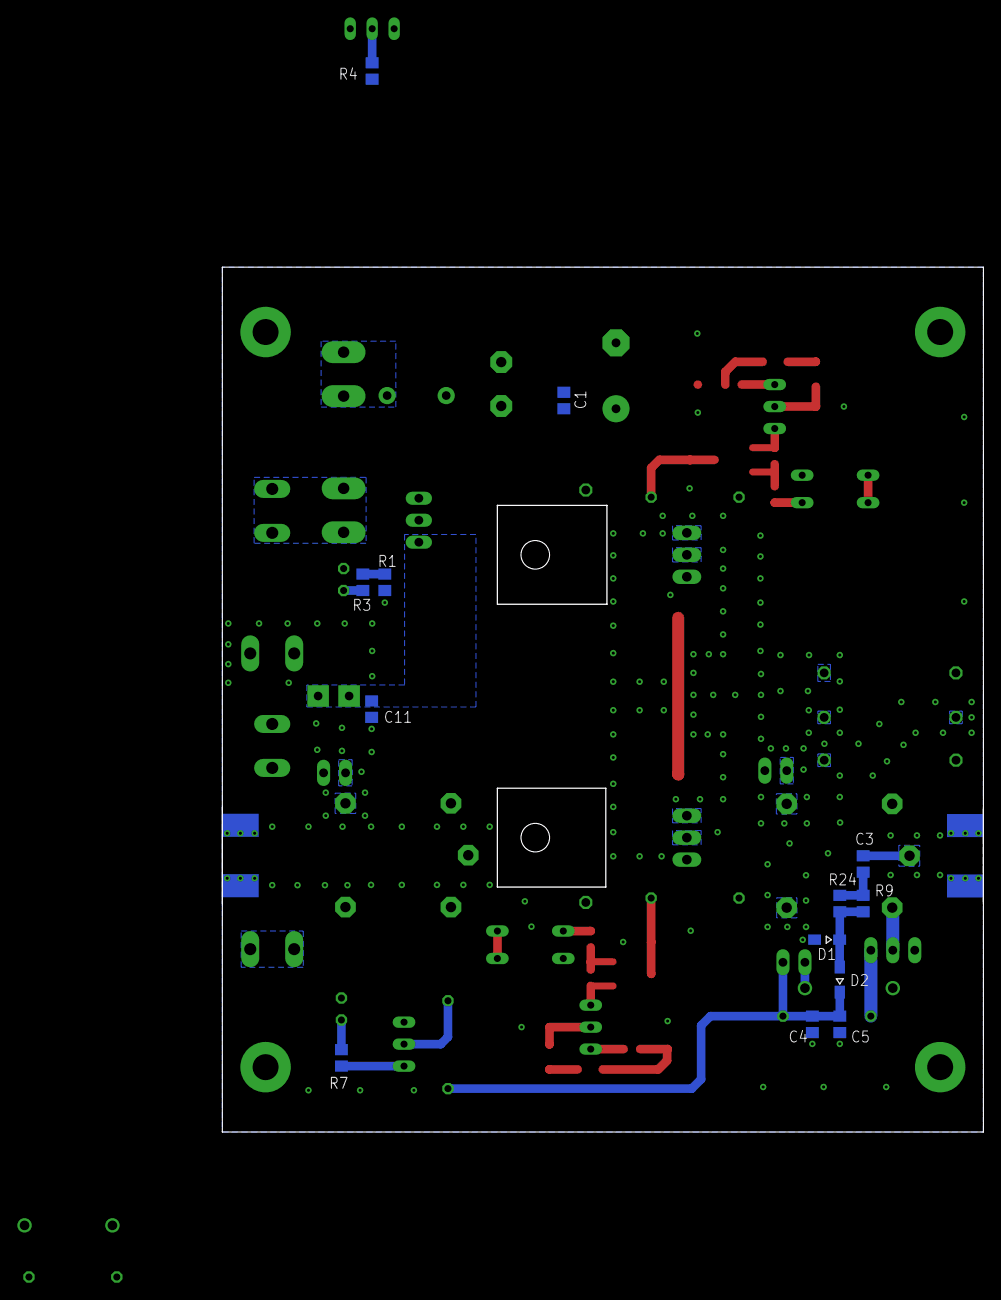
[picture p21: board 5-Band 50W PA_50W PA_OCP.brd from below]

Board: 2 copper layers, 88.0 x 100.0 mm, 87 parts (13 on the bottom side), 51 nets.
